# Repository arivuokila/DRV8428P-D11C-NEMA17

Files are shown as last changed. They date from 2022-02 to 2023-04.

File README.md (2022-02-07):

# DRV8428P-D11C-NEMA17

Modification of the board by Neil Gershenfeld http://academy.cba.mit.edu/classes/output_devices/DRV8428/hello.DRV8428-D11C-NEMA17.png for DRV8428P bipolar stepper or dual brushed motor driver

DRV8428P https://www.ti.com/store/ti/en/p/product/?p=DRV8428PPWPR

Bootloader for the D11C can be burnt with for example fabbed SWD programmer: https://gitlab.fabcloud.org/pub/programmers/programmer-swd-d11c

After the D11C has the bootloader, programs can be uploaded directly via USB with e.g. Arduino IDE
https://github.com/qbolsee/ArduinoCore-fab-sam
https://raw.githubusercontent.com/qbolsee/ArduinoCore-fab-sam/master/json/package_Fab_SAM_index.json

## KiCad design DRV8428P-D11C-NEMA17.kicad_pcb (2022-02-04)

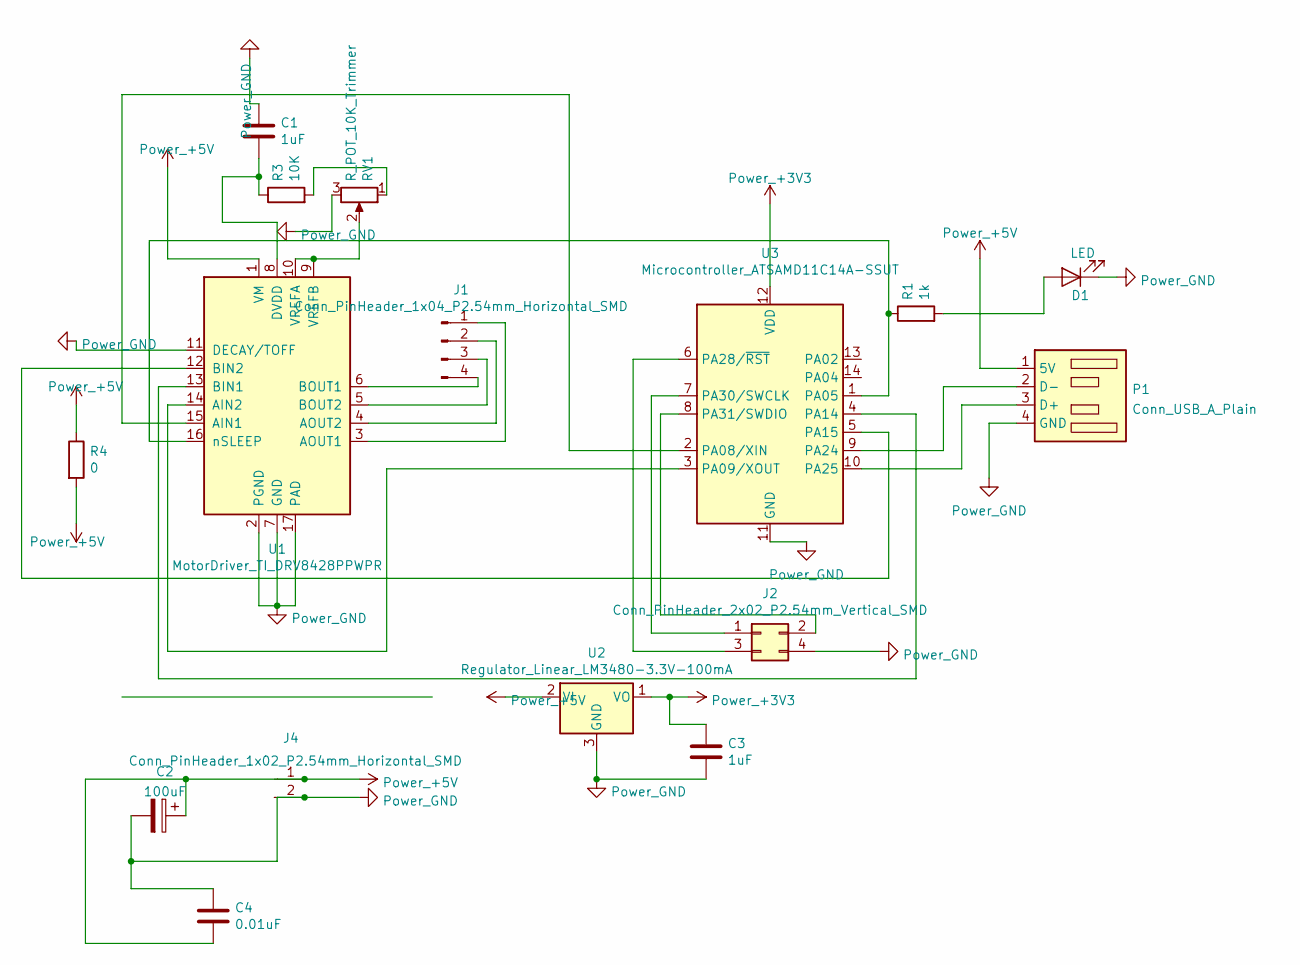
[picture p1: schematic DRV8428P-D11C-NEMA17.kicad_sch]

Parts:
C1, C3: 1uF; C_1206
C2: 100uF; CP_Elec_10x10mm
C4: 0.01uF; C_1206
D1: LED; LED_1206
J1: Conn_PinHeader_1x04_P2.54mm_Horizontal_SMD; PinHeader_1x04_P2.54mm_Horizontal_SMD
J2: Conn_PinHeader_2x02_P2.54mm_Vertical_SMD; PinHeader_2x02_P2.54mm_Vertical_SMD
J4: Conn_PinHeader_1x02_P2.54mm_Horizontal_SMD; PinHeader_UPDI_01x02_P2.54mm_Horizontal_SMD
P1: Conn_USB_A_Plain
R1: 1k; R_1206
R3: 10K; R_1206
R4: 0; R_1206
RV1: R_POT_10K_Trimmer; Potentiometer_TT_Model-23_4.5x5.0x3.0mm
U1: MotorDriver_TI_DRV8428PPWPR; HTSSOP-16
U2: Regulator_Linear_LM3480-3.3V-100mA; SOT-23
U3: Microcontroller_ATSAMD11C14A-SSUT; SOIC-14_3.9x8.7mm_P1.27mm

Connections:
+3V3: C3.1, U2.1 (VO), U3.12 (VDD)
+5V: C2.1, C4.2, J4.1, P1.1 (5V), R4.1, R4.2, U1.1 (VM), U2.2 (VI)
GND: C1.1, C2.2, C3.2, C4.1, D1.1 (K), J2.4, J4.2, P1.4 (GND), RV1.3, U1.2 (PGND), U1.7 (GND), U1.11 (DECAY/TOFF), U1.17 (PAD), U2.3 (GND), U3.11 (GND)
unnamed: C1.2, R3.1, U1.8 (DVDD)
unnamed: J1.1, U1.3 (AOUT1)
unnamed: J1.2, U1.4 (AOUT2)
unnamed: J1.3, U1.5 (BOUT2)
unnamed: J1.4, U1.6 (BOUT1)
unnamed: J2.1, U3.7 (PA30/SWCLK)
unnamed: J2.2, U3.8 (PA31/SWDIO)
unnamed: J2.3, U3.6 (PA28/~RST)
unnamed: P1.2 (D-), U3.9 (PA24)
unnamed: P1.3 (D+), U3.10 (PA25)
unnamed: D1.2 (A), R1.2
unnamed: R3.2, RV1.1
unnamed: RV1.2, U1.9 (VREFB), U1.10 (VREFA)
unnamed: U1.12 (BIN2), U3.5 (PA15)
unnamed: U1.14 (AIN2), U3.3 (PA09/XOUT)
unnamed: R1.1, U1.16 (nSLEEP), U3.1 (PA05)
unnamed: U1.15 (AIN1), U3.2 (PA08/XIN)
unnamed: U1.13 (BIN1), U3.4 (PA14)

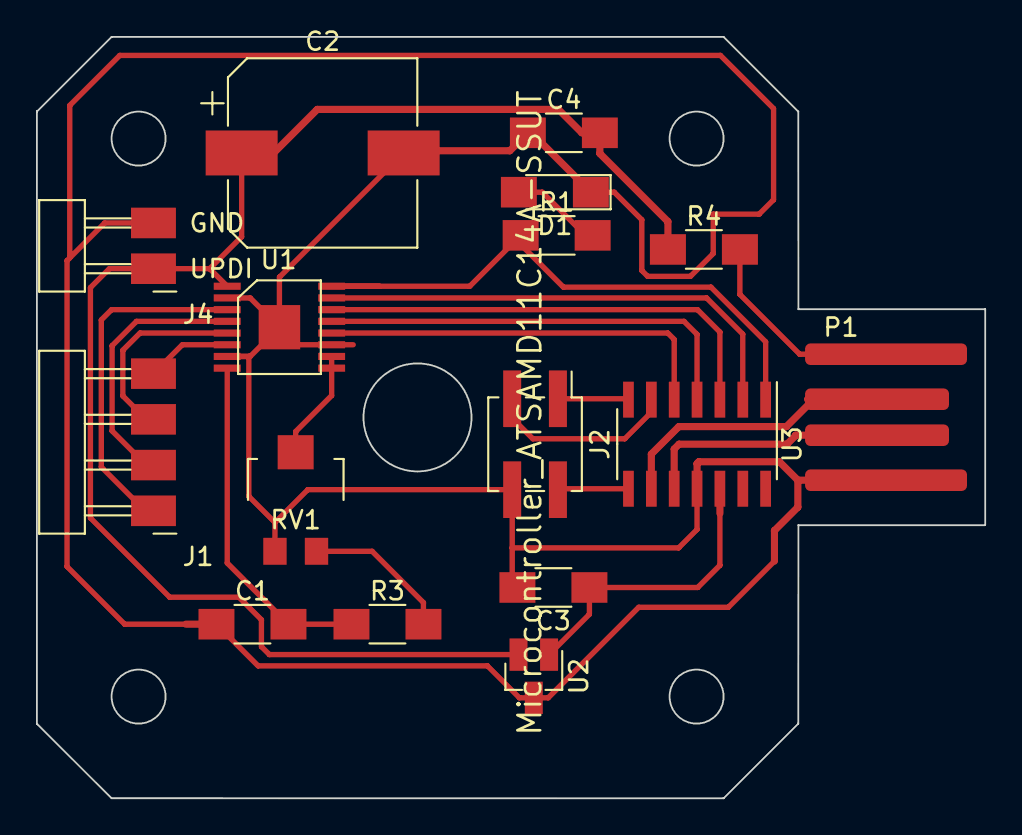
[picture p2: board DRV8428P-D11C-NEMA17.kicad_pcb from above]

Board: 2 copper layers, 52.7 x 42.3 mm, 16 parts (0 on the bottom side), 21 nets.

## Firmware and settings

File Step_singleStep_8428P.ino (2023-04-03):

#define SLEEP 5
#define AIN1 8
#define AIN2 9
#define BIN1 14
#define BIN2 15
#define DELAYHIGH 5000

void setup() {
  Serial.begin(115200);
   digitalWrite(SLEEP,LOW);
   pinMode(SLEEP,OUTPUT);
   digitalWrite(AIN1,LOW);
   pinMode(AIN1,OUTPUT);
   digitalWrite(AIN2,LOW);
   pinMode(AIN2,OUTPUT);
   digitalWrite(BIN1,LOW);
   pinMode(BIN1,OUTPUT);
   digitalWrite(BIN2,LOW);
   pinMode(BIN2,OUTPUT);
   }

void loop() {
 if (Serial.available()) {
      char c = Serial.read();
      if (c == 'f') {
        digitalWrite(SLEEP,HIGH);
        step();
        digitalWrite(SLEEP,LOW);                           
         }
      else if (c == 'r') {
         digitalWrite(SLEEP,HIGH);
         stepBack();
         digitalWrite(SLEEP,LOW);
         }
 }
   
}

void step(){
      digitalWrite(AIN1,HIGH);
      digitalWrite(AIN2,LOW);
      digitalWrite(BIN1,HIGH);
      digitalWrite(BIN2,LOW);
      delayMicroseconds(DELAYHIGH);
     
      digitalWrite(AIN1,LOW);
      digitalWrite(AIN2,HIGH);
      digitalWrite(BIN1,HIGH);
      digitalWrite(BIN2,LOW);
      delayMicroseconds(DELAYHIGH);
      
      digitalWrite(AIN1,LOW);
      digitalWrite(AIN2,HIGH);
      digitalWrite(BIN1,LOW);
      digitalWrite(BIN2,HIGH);
      delayMicroseconds(DELAYHIGH);
      
      digitalWrite(AIN1,HIGH);
      digitalWrite(AIN2,LOW);
      digitalWrite(BIN1,LOW);
      digitalWrite(BIN2,HIGH);
      delayMicroseconds(DELAYHIGH);
}

void stepBack(){
      digitalWrite(AIN1,HIGH);
      digitalWrite(AIN2,LOW);
      digitalWrite(BIN1,LOW);
      digitalWrite(BIN2,HIGH);
      delayMicroseconds(DELAYHIGH);

      digitalWrite(AIN1,LOW);
      digitalWrite(AIN2,HIGH);
      digitalWrite(BIN1,LOW);
      digitalWrite(BIN2,HIGH);
      delayMicroseconds(DELAYHIGH);
      
      digitalWrite(AIN1,LOW);
      digitalWrite(AIN2,HIGH);
      digitalWrite(BIN1,HIGH);
      digitalWrite(BIN2,LOW);
      delayMicroseconds(DELAYHIGH);
      
      digitalWrite(AIN1,HIGH);
      digitalWrite(AIN2,LOW);
      digitalWrite(BIN1,HIGH);
      digitalWrite(BIN2,LOW);
      delayMicroseconds(DELAYHIGH);   
}

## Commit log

2022-01-25 Design files for Kicad
    [DRV8428P-D11C-NEMA17.kicad_pcb, DRV8428P-D11C-NEMA17.kicad_sch]
2022-01-25 Create Gerber
2022-01-28 USB fixed
    [DRV8428P-D11C-NEMA17-Edge_Cuts.gbr, DRV8428P-D11C-NEMA17-F_Cu.gbr]
2022-01-28 Updated board
    [DRV8428P-D11C-NEMA17.kicad_pcb]
2022-02-04 Updating the design
    [DRV8428P-D11C-NEMA17.kicad_pcb, DRV8428P-D11C-NEMA17.kicad_sch]
2022-02-04 Updating the gerbers
    [DRV8428P-D11C-NEMA17-Edge_Cuts.gbr, DRV8428P-D11C-NEMA17-F_Cu.gbr]
2023-04-03 Add files via upload
    Code to run single steps with f and r buttons via serial 115200 bps
